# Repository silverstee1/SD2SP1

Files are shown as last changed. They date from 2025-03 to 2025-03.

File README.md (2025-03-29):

# SD2SP1
MicroSD adapter PCB for SP1 on Nintendo GameCube

Due to the way the SP1 port is handled on the gamecube the speeds of the adapter are limited to v1.0 speeds like the original adapters for other ports, ex. WiiSD, GC2SD, SD2SP2 which didn't have added OR gate component to achieve the higher v2.0 speeds.

Make sure to use the latest version of Swiss in order to use this adapter in SP1 Slot on the bottom of the gamecube, the pcb is marked which orientation it is to be inserted and can be covered with SP1 Port cover once installed.

https://github.com/emukidid/swiss-gc

20250105_151028-min

20240819_205530-min

Screenshot_20250329-071652_Gallery-min

Screenshot_20250329-071736_Gallery-min

# PCB Order

Make sure to order the PCB from a fab such as JLCPCB with a 1.2mm thickness and a ENIG surface finish for longevity, HASL will work too but won't be as durable on the edge connector in the long run.

# BOM

| Designator | Description | DigiKey Part # | LCSC Part # |
| --- | --- | --- | --- |
| C1 | 0402 22u Capactior (10V Min) | 490-GRM158R61A226ME15DCT-ND | C3845593 |
| J1 | MicroSD Slot | 2223-MSD-4-ACT-ND | C113206 |
| PCB | Order From Fab ex. JLCPCB 1.2mm thickness ENIG |||

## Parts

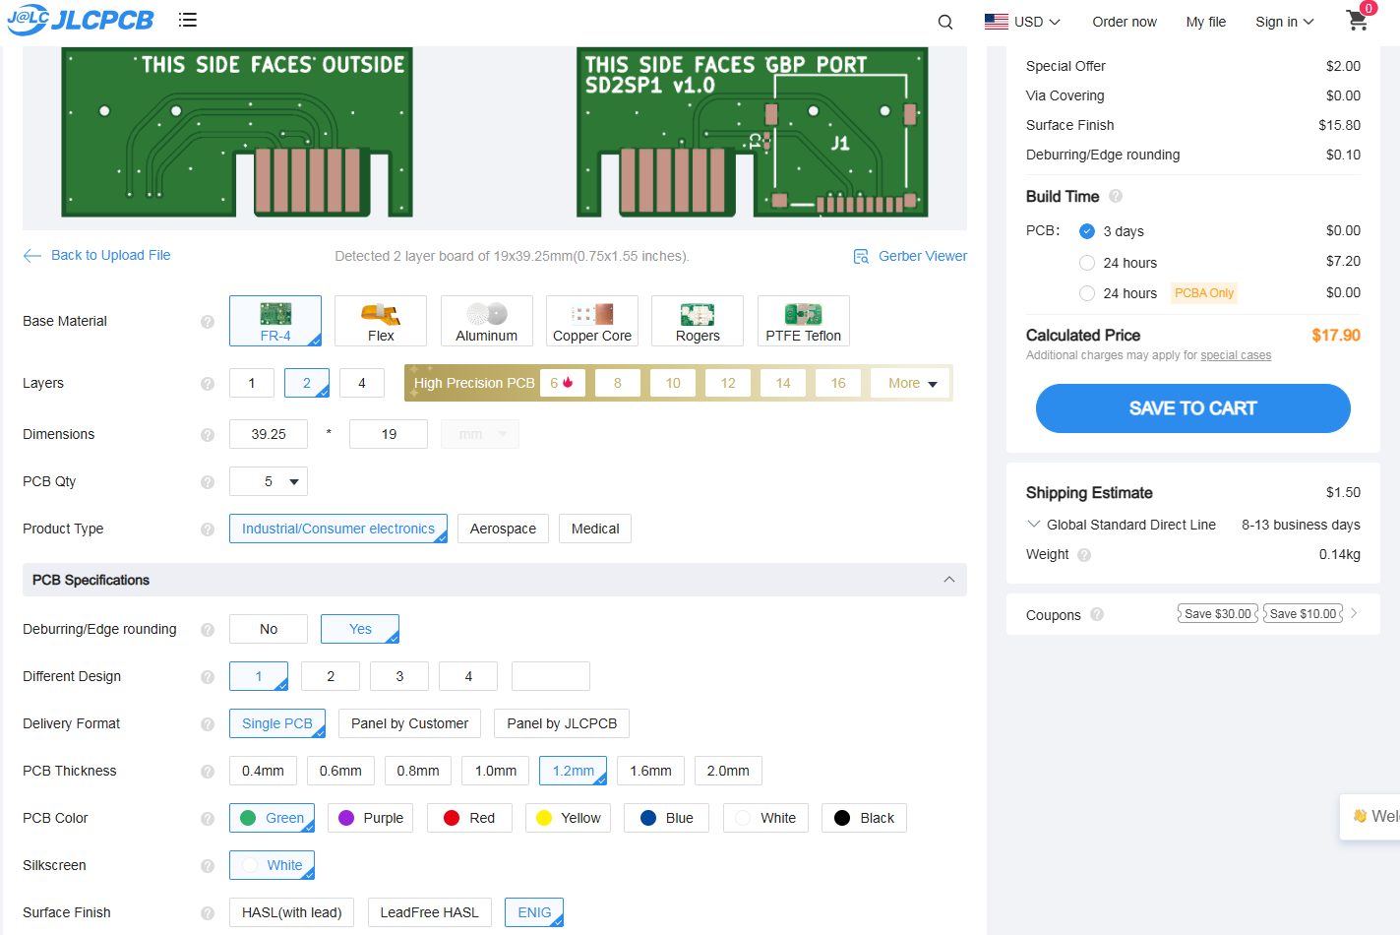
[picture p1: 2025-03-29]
PCB/JLCPCB order example.png

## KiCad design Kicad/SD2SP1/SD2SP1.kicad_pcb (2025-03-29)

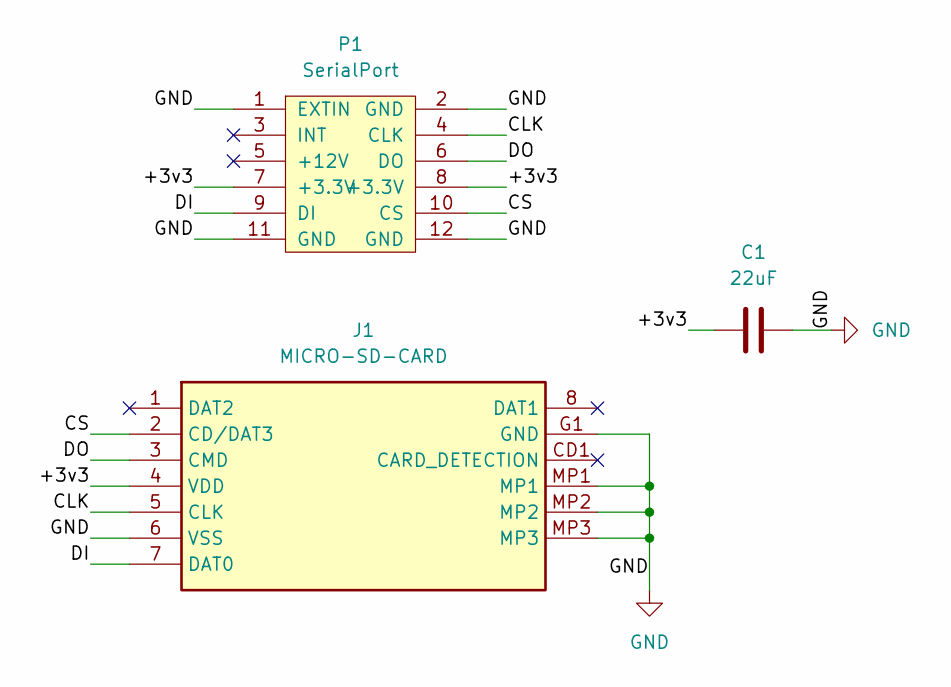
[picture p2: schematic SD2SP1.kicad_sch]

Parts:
C1: 22uF; C_0402_1005Metric_Pad0.74x0.62mm_HandSolder
J1: MICRO-SD-CARD; MICROSDCARD; Mouser Part Number 909-MICRO-SD-CARD
P1: SerialPort; SP1_FootPrint

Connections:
/+3v3: C1.1, J1.4 (VDD), P1.7 (+3.3V), P1.8 (+3.3V)
/CLK: J1.5 (CLK), P1.4 (CLK)
/CS: J1.2 (CD/DAT3), P1.10 (CS)
/DI: J1.7 (DAT0), P1.9 (DI)
/DO: J1.3 (CMD), P1.6 (DO)
GND: C1.2, J1.6 (VSS), J1.G1 (GND), J1.MP1, J1.MP2, J1.MP3, P1.1 (EXTIN), P1.2 (GND), P1.11 (GND), P1.12 (GND)

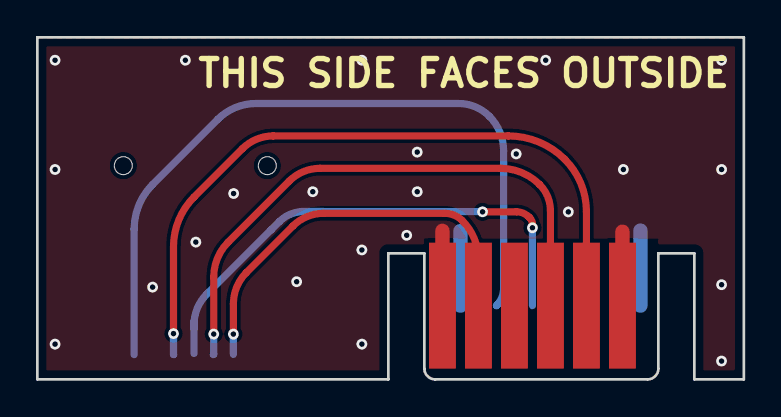
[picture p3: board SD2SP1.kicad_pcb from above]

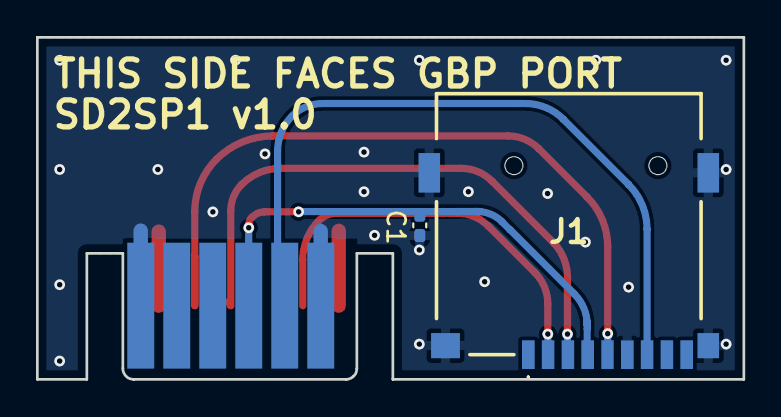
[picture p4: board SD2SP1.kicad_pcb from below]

Board: 2 copper layers, 39.2 x 19.0 mm, 3 parts (3 on the bottom side), 6 nets.
